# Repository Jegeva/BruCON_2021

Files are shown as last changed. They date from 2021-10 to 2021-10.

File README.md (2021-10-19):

BruCON 2021
=
This is the firmware and pcb for brucon badge 

as of released at the conference **ie. including** :

* the mistake that needs a bodge (vbat to the sensor, backlights and leds missing a bit of trace) and 
* the mistake with the connector (don't use the one refed in the kicad docs, it is keyed down instead of up)

Licenses :
=

-my (**ugly**) firmware code and the PCB are CERN-OHL-P

-the gasmask art is CC/NA by Ray Harvey

-Espressif stuff : 
[see here](https://docs.espressif.com/projects/esp-idf/en/latest/esp32/COPYRIGHT.html)

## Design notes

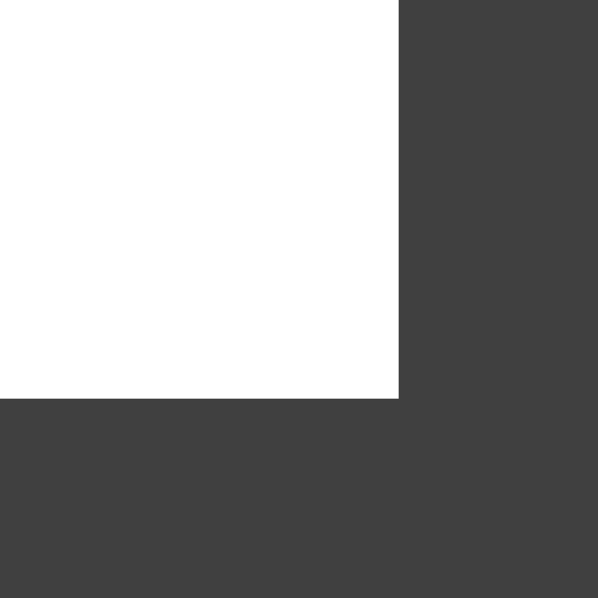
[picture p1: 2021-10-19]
pcb/.svg2shenzhen-cache/images/Dwgs.User_g1427.png

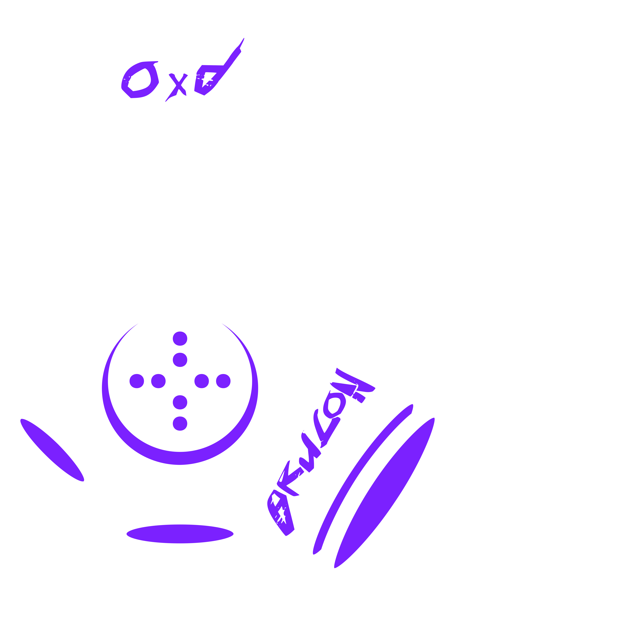
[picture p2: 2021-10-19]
pcb/.svg2shenzhen-cache/images/F.Mask_g1423.png

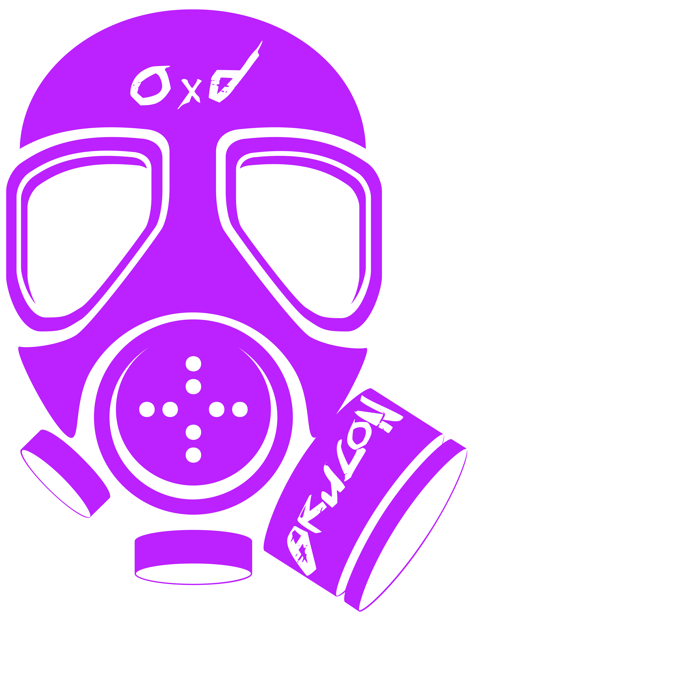
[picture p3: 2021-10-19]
pcb/.svg2shenzhen-cache/images/F.SilkS_g1425.png

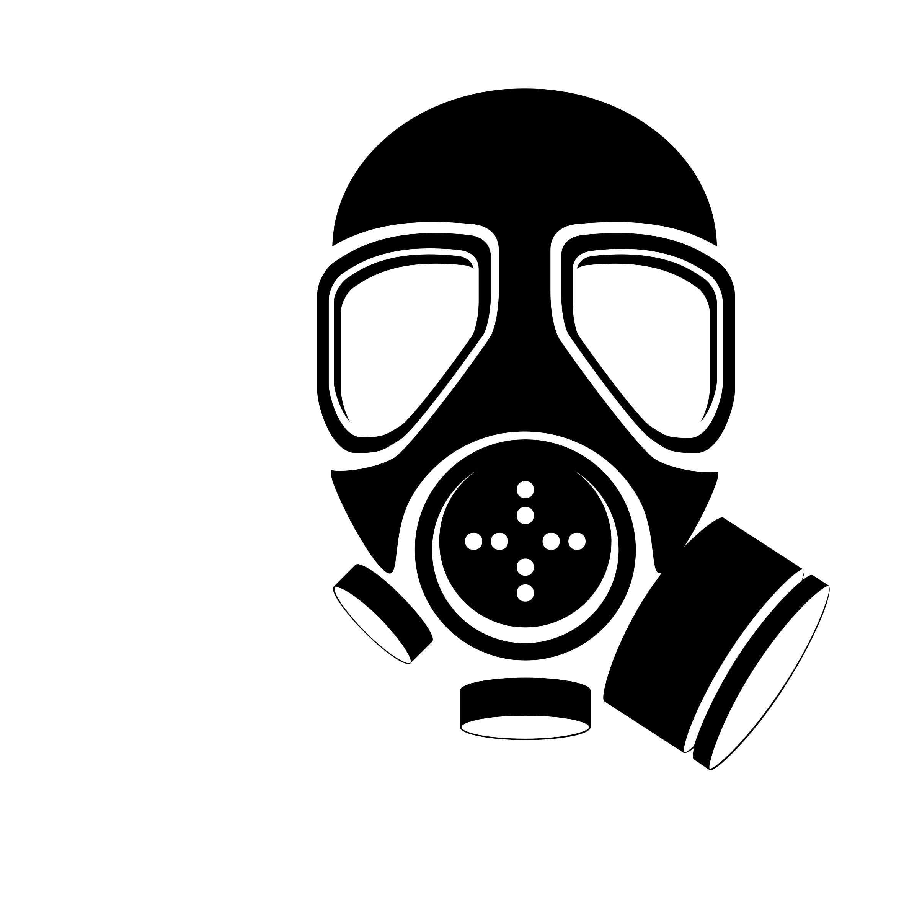
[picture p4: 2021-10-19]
pcb/.svg2shenzhen-cache/images/F.SilkS_g1537.png

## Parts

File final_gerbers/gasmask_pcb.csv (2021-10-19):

Source: | /home/jg/work/brucon/0xd/pcb/gasmask_pcb.kicad_sch
Date: | Wed Sep 15 12:33:13 2021
Tool: | Eeschema (5.99.0-10282-g296a9df530)
Generator: | /usr/local/share/kicad/plugins/bom_csv_grouped_by_value.py
Component Count: | 74
Individual Components:
Item | Qty | Reference(s) | Value | LibPart | Footprint | Datasheet
 |  | C1 | 1uF | Device:C | Capacitor_SMD:C_0805_2012Metric | ~
 |  | C2 | 1uF | Device:C | Capacitor_SMD:C_0805_2012Metric | ~
 |  | C3 | 1uF | Device:C | Capacitor_SMD:C_0805_2012Metric | ~
 |  | C4 | 4.7uF | Device:C | Capacitor_SMD:C_0805_2012Metric | ~
 |  | C5 | 0.1uF | Device:C | Capacitor_SMD:C_0805_2012Metric | ~
 |  | C6 | 4.7uF | Device:C | Capacitor_SMD:C_0805_2012Metric | ~
 |  | C7 | 0.1uF | Device:C | Capacitor_SMD:C_0805_2012Metric | ~
 |  | C9 | 4.7uF | Device:C | Capacitor_SMD:C_0805_2012Metric | ~
 |  | C10 | 4.7uF | Device:C | Capacitor_SMD:C_0805_2012Metric | ~
 |  | C11 | 10uF | Device:C | Capacitor_SMD:C_0805_2012Metric | ~
 |  | C13 | 10uF | Device:C | Capacitor_SMD:C_0805_2012Metric | ~
 |  | C14 | 10uF | Device:C | Capacitor_SMD:C_0805_2012Metric | ~
 |  | CONN_BATT1 | Conn_01x02 | Connector_Generic:Conn_01x02 | brucon_badge:JST-PH-SM4-TB-2 | ~
 |  | D1 | LED | Device:LED | LED_SMD:LED_0603_1608Metric | ~
 |  | D2 | FM5817 | Device:D_Schottky | brucon_badge:DO-214-FM5817 | ~
 |  | D3 | LED | Device:LED | LED_SMD:LED_0603_1608Metric | ~
 |  | D4 | LED_RGBA | Device:LED_RGBA | LED_SMD:LED_Cree-PLCC4_2x2mm_CW | ~
 |  | J1 | Hirose DF23C-10DS-0.5 | Connector_Generic:Conn_02x05_Counter_Clockwise | brucon_badge:DF23C-10DS-0.5V | ~
 |  | J2 | Conn_02x02_Top_Bottom | Connector_Generic:Conn_02x02_Top_Bottom | Connector_PinHeader_2.54mm:PinHeader_2x02_P2.54mm_Vertical | ~
 |  | J3 | Conn_01x02 | Connector_Generic:Conn_01x02 | Connector_PinHeader_2.54mm:PinHeader_1x02_P2.54mm_Vertical | ~
 |  | J4 | USB_B_Micro | Connector:USB_B_Micro | Connector_USB:USB_Micro-B_Molex_47346-0001 | ~
 |  | J5 | Conn_01x01_Female | Connector:Conn_01x01_Female | brucon_badge:touch_10mm | ~
 |  | J6 | Conn_01x01_Female | Connector:Conn_01x01_Female | brucon_badge:touch_10mm | ~
 |  | J7 | Conn_01x01_Female | Connector:Conn_01x01_Female | brucon_badge:touch_10mm | ~
 |  | J8 | Conn_01x01_Female | Connector:Conn_01x01_Female | brucon_badge:touch_10mm | ~
 |  | J9 | Conn_01x01_Female | Connector:Conn_01x01_Female | brucon_badge:touch_10mm | ~
 |  | J10 | Conn_01x01_Female | Connector:Conn_01x01_Female | brucon_badge:touch_10mm | ~
 |  | M2 | 10uH | BruCON_0x0a-rescue:L-adafruit | Inductor_SMD:L_0805_2012Metric
 |  | q1 | NX7002aks_small | gasmask:NX7002aks_small | Package_TO_SOT_SMD:SOT-363_SC-70-6
 |  | Q2 | BT3904 | Device:Q_NPN_BEC | Package_TO_SOT_SMD:SOT-23 | ~
 |  | Q3 | BT3904 | Device:Q_NPN_BEC | Package_TO_SOT_SMD:SOT-23 | ~
 |  | Q4 | NX7002aks_small | gasmask:NX7002aks_small | Package_TO_SOT_SMD:SOT-363_SC-70-6
 |  | R1 | 100k | Device:R | Resistor_SMD:R_0805_2012Metric | ~
 |  | R2 | 10k | Device:R | Resistor_SMD:R_0805_2012Metric | ~
 |  | R3 | 10k | Device:R | Resistor_SMD:R_0805_2012Metric | ~
 |  | R4 | 10K | Device:R | Resistor_SMD:R_0805_2012Metric | ~
 |  | R5 | 10K | Device:R | Resistor_SMD:R_0805_2012Metric | ~
 |  | R6 | 22.1k | Device:R | Resistor_SMD:R_0805_2012Metric | ~
 |  | R7 | 47.5k | Device:R | Resistor_SMD:R_0805_2012Metric | ~
 |  | R8 | 1.0k 1% | Device:R | Resistor_SMD:R_0805_2012Metric | ~
 |  | R9 | 1.0k 1% | Device:R | Resistor_SMD:R_0805_2012Metric | ~
 |  | R10 | 1.0k 1% | Device:R | Resistor_SMD:R_0805_2012Metric | ~
 |  | R11 | 1 M | Device:R | Resistor_SMD:R_0805_2012Metric | ~
 |  | R12 | 10k | Device:R | Resistor_SMD:R_0805_2012Metric | ~
 |  | R13 | 100k 1% | Device:R | Resistor_SMD:R_0805_2012Metric | ~
 |  | R14 | 100k 1% | Device:R | Resistor_SMD:R_0805_2012Metric | ~
 |  | R15 | 2k 1% | Device:R | Resistor_SMD:R_0805_2012Metric | ~
 |  | R16 | 9.0k 1% | Device:R | Resistor_SMD:R_0805_2012Metric | ~
 |  | R17 | 1.5k 1% | Device:R | Resistor_SMD:R_0805_2012Metric | ~
 |  | R18 | 2k 1% | Device:R | Resistor_SMD:R_0805_2012Metric | ~
 |  | R19 | 27k 1% | Device:R | Resistor_SMD:R_0805_2012Metric | ~
 |  | R20 | 100k 1% | Device:R | Resistor_SMD:R_0805_2012Metric | ~
 |  | R21 | 1.47k 1% | Device:R | Resistor_SMD:R_0805_2012Metric | ~
 |  | R22 | 1.47k 1% | Device:R | Resistor_SMD:R_0805_2012Metric | ~
 |  | R23 | 10k 1% | Device:R | Resistor_SMD:R_0805_2012Metric | ~
 |  | R24 | 5k 1% | Device:R | Resistor_SMD:R_0805_2012Metric | ~
 |  | R25 | 100 | Device:R | Resistor_SMD:R_0805_2012Metric | ~
 |  | R26 | 1k 1% | Device:R | Resistor_SMD:R_0805_2012Metric | ~
 |  | R27 | 50 | Device:R | Resistor_SMD:R_0805_2012Metric | ~
 |  | R28 | 5k | Device:R | Resistor_SMD:R_0805_2012Metric | ~
 |  | R29 | 10k | Device:R | Resistor_SMD:R_0805_2012Metric | ~
 |  | R30 | 10k | Device:R | Resistor_SMD:R_0805_2012Metric | ~
 |  | R31 | 20k 1% | Device:R | Resistor_SMD:R_0805_2012Metric | ~
 |  | R32 | 50 | Device:R | Resistor_SMD:R_0805_2012Metric | ~
 |  | SW1 | SW_DPDT_x2 | Switch:SW_DPDT_x2 | brucon_badge:JS102000-SAQN | ~
 |  | SW_PROG1 | SW_SPST | Switch:SW_SPST | brucon_badge:FSM4JSMATR | ~
 |  | SW_RESET1 | SW_SPST | Switch:SW_SPST | brucon_badge:FSM4JSMATR | ~
 |  | U1 | ESP32-WROOM | ESP32-footprints-Shem-Lib:ESP32-WROOM | brucon_badge:ESP32-WROOM
 |  | U2 | CP2102N-A01-GQFN24 | Interface_USB:CP2102N-A01-GQFN24 | Package_DFN_QFN:QFN-24-1EP_4x4mm_P0.5mm_EP2.6x2.6mm | http://www.silabs.com/support%20documents/technicaldocs/cp2102n-datasheet.pdf
 |  | U3 | NCP5661 | BruCON_0x0a-rescue:NCP5661-Brucon | brucon_badge:DFN6-3.6x2.15mmP0.95
 |  | U4 | LM3658SD | LM3658SD:LM3658SD | IC_TPS61087DSCR
 |  | U5 | MIC2288YD5 | BruCON_0x0a-rescue:MIC2288YD5-Brucon | Package_TO_SOT_SMD:SOT-23-5
 |  | U6 | MQ-6 | Sensor_Gas:MQ-6 | brucon_badge:MQ-3 | https://www.winsen-sensor.com/d/files/semiconductor/mq-6.pdf
 |  | U8 | MCP112-315 | BruCON_0x0a-rescue:MCP112-315-Brucon | Package_TO_SOT_SMD:SOT-23
Collated Components:
Item | Qty | Reference(s) | Value | LibPart | Footprint | Datasheet
1 | 3 | C1, C2, C3 | 1uF | Device:C | Capacitor_SMD:C_0805_2012Metric | ~
2 | 4 | C4, C6, C9, C10 | 4.7uF | Device:C | Capacitor_SMD:C_0805_2012Metric | ~
3 | 2 | C5, C7 | 0.1uF | Device:C | Capacitor_SMD:C_0805_2012Metric | ~
4 | 3 | C11, C13, C14 | 10uF | Device:C | Capacitor_SMD:C_0805_2012Metric | ~
5 | 1 | CONN_BATT1 | Conn_01x02 | Connector_Generic:Conn_01x02 | brucon_badge:JST-PH-SM4-TB-2 | ~
6 | 2 | D1, D3 | LED | Device:LED | LED_SMD:LED_0603_1608Metric | ~
7 | 1 | D2 | FM5817 | Device:D_Schottky | brucon_badge:DO-214-FM5817 | ~
8 | 1 | D4 | LED_RGBA | Device:LED_RGBA | LED_SMD:LED_Cree-PLCC4_2x2mm_CW | ~
9 | 1 | J1 | Hirose DF23C-10DS-0.5 | Connector_Generic:Conn_02x05_Counter_Clockwise | brucon_badge:DF23C-10DS-0.5V | ~
10 | 1 | J2 | Conn_02x02_Top_Bottom | Connector_Generic:Conn_02x02_Top_Bottom | Connector_PinHeader_2.54mm:PinHeader_2x02_P2.54mm_Vertical | ~
11 | 1 | J3 | Conn_01x02 | Connector_Generic:Conn_01x02 | Connector_PinHeader_2.54mm:PinHeader_1x02_P2.54mm_Vertical | ~
12 | 1 | J4 | USB_B_Micro | Connector:USB_B_Micro | Connector_USB:USB_Micro-B_Molex_47346-0001 | ~
13 | 6 | J5, J6, J7, J8, J9, J10 | Conn_01x01_Female | Connector:Conn_01x01_Female | brucon_badge:touch_10mm | ~
14 | 1 | M2 | 10uH | BruCON_0x0a-rescue:L-adafruit | Inductor_SMD:L_0805_2012Metric
15 | 2 | q1, Q4 | NX7002aks_small | gasmask:NX7002aks_small | Package_TO_SOT_SMD:SOT-363_SC-70-6
16 | 2 | Q2, Q3 | BT3904 | Device:Q_NPN_BEC | Package_TO_SOT_SMD:SOT-23 | ~
17 | 1 | R1 | 100k | Device:R | Resistor_SMD:R_0805_2012Metric | ~
18 | 5 | R2, R3, R12, R29, R30 | 10k | Device:R | Resistor_SMD:R_0805_2012Metric | ~
19 | 2 | R4, R5 | 10K | Device:R | Resistor_SMD:R_0805_2012Metric | ~
20 | 1 | R6 | 22.1k | Device:R | Resistor_SMD:R_0805_2012Metric | ~
21 | 1 | R7 | 47.5k | Device:R | Resistor_SMD:R_0805_2012Metric | ~
22 | 3 | R8, R9, R10 | 1.0k 1% | Device:R | Resistor_SMD:R_0805_2012Metric | ~
23 | 1 | R11 | 1 M | Device:R | Resistor_SMD:R_0805_2012Metric | ~
24 | 3 | R13, R14, R20 | 100k 1% | Device:R | Resistor_SMD:R_0805_2012Metric | ~
25 | 2 | R15, R18 | 2k 1% | Device:R | Resistor_SMD:R_0805_2012Metric | ~
26 | 1 | R16 | 9.0k 1% | Device:R | Resistor_SMD:R_0805_2012Metric | ~
27 | 1 | R17 | 1.5k 1% | Device:R | Resistor_SMD:R_0805_2012Metric | ~
28 | 1 | R19 | 27k 1% | Device:R | Resistor_SMD:R_0805_2012Metric | ~
29 | 2 | R21, R22 | 1.47k 1% | Device:R | Resistor_SMD:R_0805_2012Metric | ~
30 | 1 | R23 | 10k 1% | Device:R | Resistor_SMD:R_0805_2012Metric | ~
31 | 1 | R24 | 5k 1% | Device:R | Resistor_SMD:R_0805_2012Metric | ~
32 | 1 | R25 | 100 | Device:R | Resistor_SMD:R_0805_2012Metric | ~
33 | 1 | R26 | 1k 1% | Device:R | Resistor_SMD:R_0805_2012Metric | ~
34 | 2 | R27, R32 | 50 | Device:R | Resistor_SMD:R_0805_2012Metric | ~
35 | 1 | R28 | 5k | Device:R | Resistor_SMD:R_0805_2012Metric | ~
36 | 1 | R31 | 20k 1% | Device:R | Resistor_SMD:R_0805_2012Metric | ~
37 | 1 | SW1 | SW_DPDT_x2 | Switch:SW_DPDT_x2 | brucon_badge:JS102000-SAQN | ~
38 | 2 | SW_PROG1, SW_RESET1 | SW_SPST | Switch:SW_SPST | brucon_badge:FSM4JSMATR | ~
39 | 1 | U1 | ESP32-WROOM | ESP32-footprints-Shem-Lib:ESP32-WROOM | brucon_badge:ESP32-WROOM
40 | 1 | U2 | CP2102N-A01-GQFN24 | Interface_USB:CP2102N-A01-GQFN24 | Package_DFN_QFN:QFN-24-1EP_4x4mm_P0.5mm_EP2.6x2.6mm | http://www.silabs.com/support%20documents/technicaldocs/cp2102n-datasheet.pdf
41 | 1 | U3 | NCP5661 | BruCON_0x0a-rescue:NCP5661-Brucon | brucon_badge:DFN6-3.6x2.15mmP0.95
42 | 1 | U4 | LM3658SD | LM3658SD:LM3658SD | IC_TPS61087DSCR
43 | 1 | U5 | MIC2288YD5 | BruCON_0x0a-rescue:MIC2288YD5-Brucon | Package_TO_SOT_SMD:SOT-23-5
44 | 1 | U6 | MQ-6 | Sensor_Gas:MQ-6 | brucon_badge:MQ-3 | https://www.winsen-sensor.com/d/files/semiconductor/mq-6.pdf
45 | 1 | U8 | MCP112-315 | BruCON_0x0a-rescue:MCP112-315-Brucon | Package_TO_SOT_SMD:SOT-23

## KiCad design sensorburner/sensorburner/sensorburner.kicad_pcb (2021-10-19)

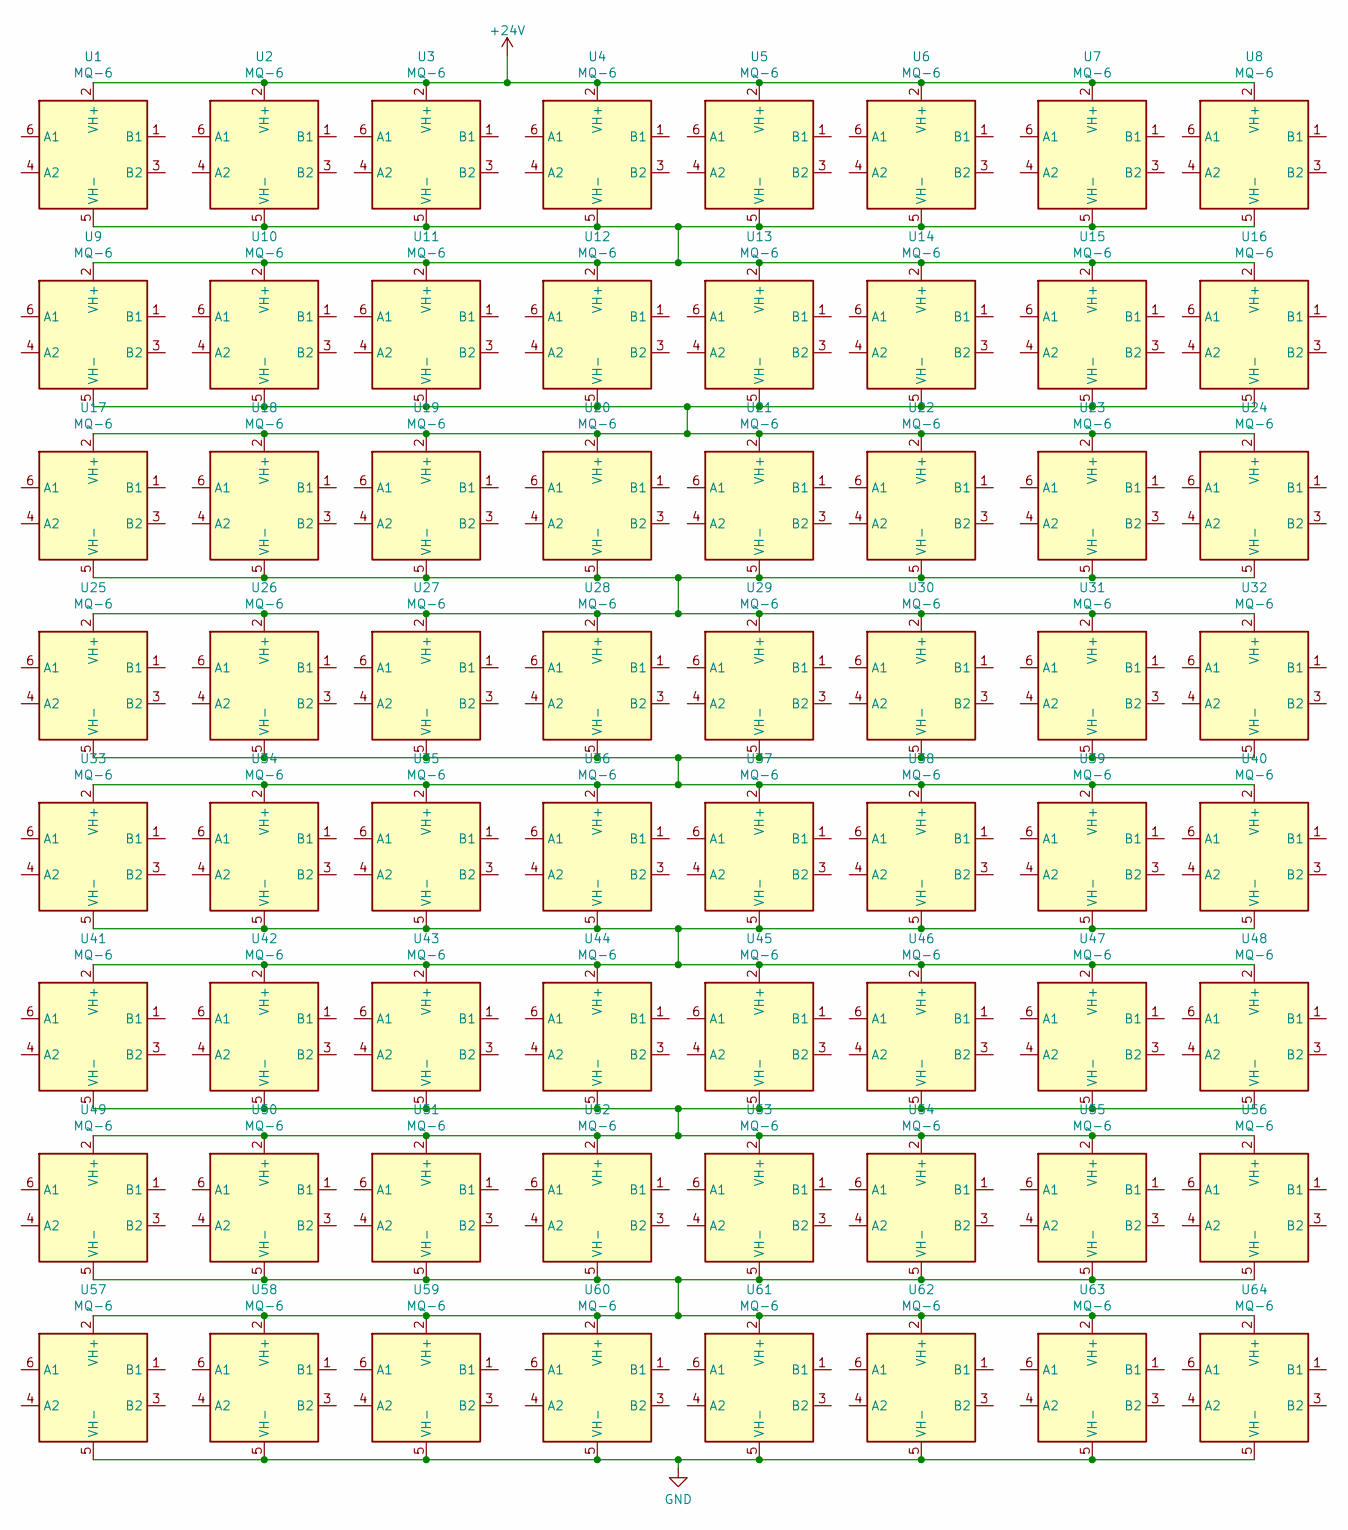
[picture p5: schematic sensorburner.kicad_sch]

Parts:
U1, U2, U3, U4, U5, U6, U7, U8, U9, U10, U11, U12, U13, U14, U15, U16, U17, U18, U19, U20, U21, U22, U23, U24, U25, U26, U27, U28, U29, U30, U31, U32, U33, U34, U35, U36, U37, U38, U39, U40, U41, U42, U43, U44, U45, U46, U47, U48, U49, U50, U51, U52, U53, U54, U55, U56, U57, U58, U59, U60, U61, U62, U63, U64: MQ-6; MQ-3-sparkfuntight

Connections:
+24V: U1.2 (VH+), U2.2 (VH+), U3.2 (VH+), U4.2 (VH+), U5.2 (VH+), U6.2 (VH+), U7.2 (VH+), U8.2 (VH+)
GND: U57.5 (VH-), U58.5 (VH-), U59.5 (VH-), U60.5 (VH-), U61.5 (VH-), U62.5 (VH-), U63.5 (VH-), U64.5 (VH-)
unnamed: U1.5 (VH-), U2.5 (VH-), U3.5 (VH-), U4.5 (VH-), U5.5 (VH-), U6.5 (VH-), U7.5 (VH-), U8.5 (VH-), U9.2 (VH+), U10.2 (VH+), U11.2 (VH+), U12.2 (VH+), U13.2 (VH+), U14.2 (VH+), U15.2 (VH+), U16.2 (VH+)
unnamed: U9.5 (VH-), U10.5 (VH-), U11.5 (VH-), U12.5 (VH-), U13.5 (VH-), U14.5 (VH-), U15.5 (VH-), U16.5 (VH-), U17.2 (VH+), U18.2 (VH+), U19.2 (VH+), U20.2 (VH+), U21.2 (VH+), U22.2 (VH+), U23.2 (VH+), U24.2 (VH+)
unnamed: U17.5 (VH-), U18.5 (VH-), U19.5 (VH-), U20.5 (VH-), U21.5 (VH-), U22.5 (VH-), U23.5 (VH-), U24.5 (VH-), U25.2 (VH+), U26.2 (VH+), U27.2 (VH+), U28.2 (VH+), U29.2 (VH+), U30.2 (VH+), U31.2 (VH+), U32.2 (VH+)
unnamed: U25.5 (VH-), U26.5 (VH-), U27.5 (VH-), U28.5 (VH-), U29.5 (VH-), U30.5 (VH-), U31.5 (VH-), U32.5 (VH-), U33.2 (VH+), U34.2 (VH+), U35.2 (VH+), U36.2 (VH+), U37.2 (VH+), U38.2 (VH+), U39.2 (VH+), U40.2 (VH+)
unnamed: U33.5 (VH-), U34.5 (VH-), U35.5 (VH-), U36.5 (VH-), U37.5 (VH-), U38.5 (VH-), U39.5 (VH-), U40.5 (VH-), U41.2 (VH+), U42.2 (VH+), U43.2 (VH+), U44.2 (VH+), U45.2 (VH+), U46.2 (VH+), U47.2 (VH+), U48.2 (VH+)
unnamed: U41.5 (VH-), U42.5 (VH-), U43.5 (VH-), U44.5 (VH-), U45.5 (VH-), U46.5 (VH-), U47.5 (VH-), U48.5 (VH-), U49.2 (VH+), U50.2 (VH+), U51.2 (VH+), U52.2 (VH+), U53.2 (VH+), U54.2 (VH+), U55.2 (VH+), U56.2 (VH+)
unnamed: U49.5 (VH-), U50.5 (VH-), U51.5 (VH-), U52.5 (VH-), U53.5 (VH-), U54.5 (VH-), U55.5 (VH-), U56.5 (VH-), U57.2 (VH+), U58.2 (VH+), U59.2 (VH+), U60.2 (VH+), U61.2 (VH+), U62.2 (VH+), U63.2 (VH+), U64.2 (VH+)

Board: 2 copper layers, 64 parts (0 on the bottom side), 9 nets, no tracks yet.

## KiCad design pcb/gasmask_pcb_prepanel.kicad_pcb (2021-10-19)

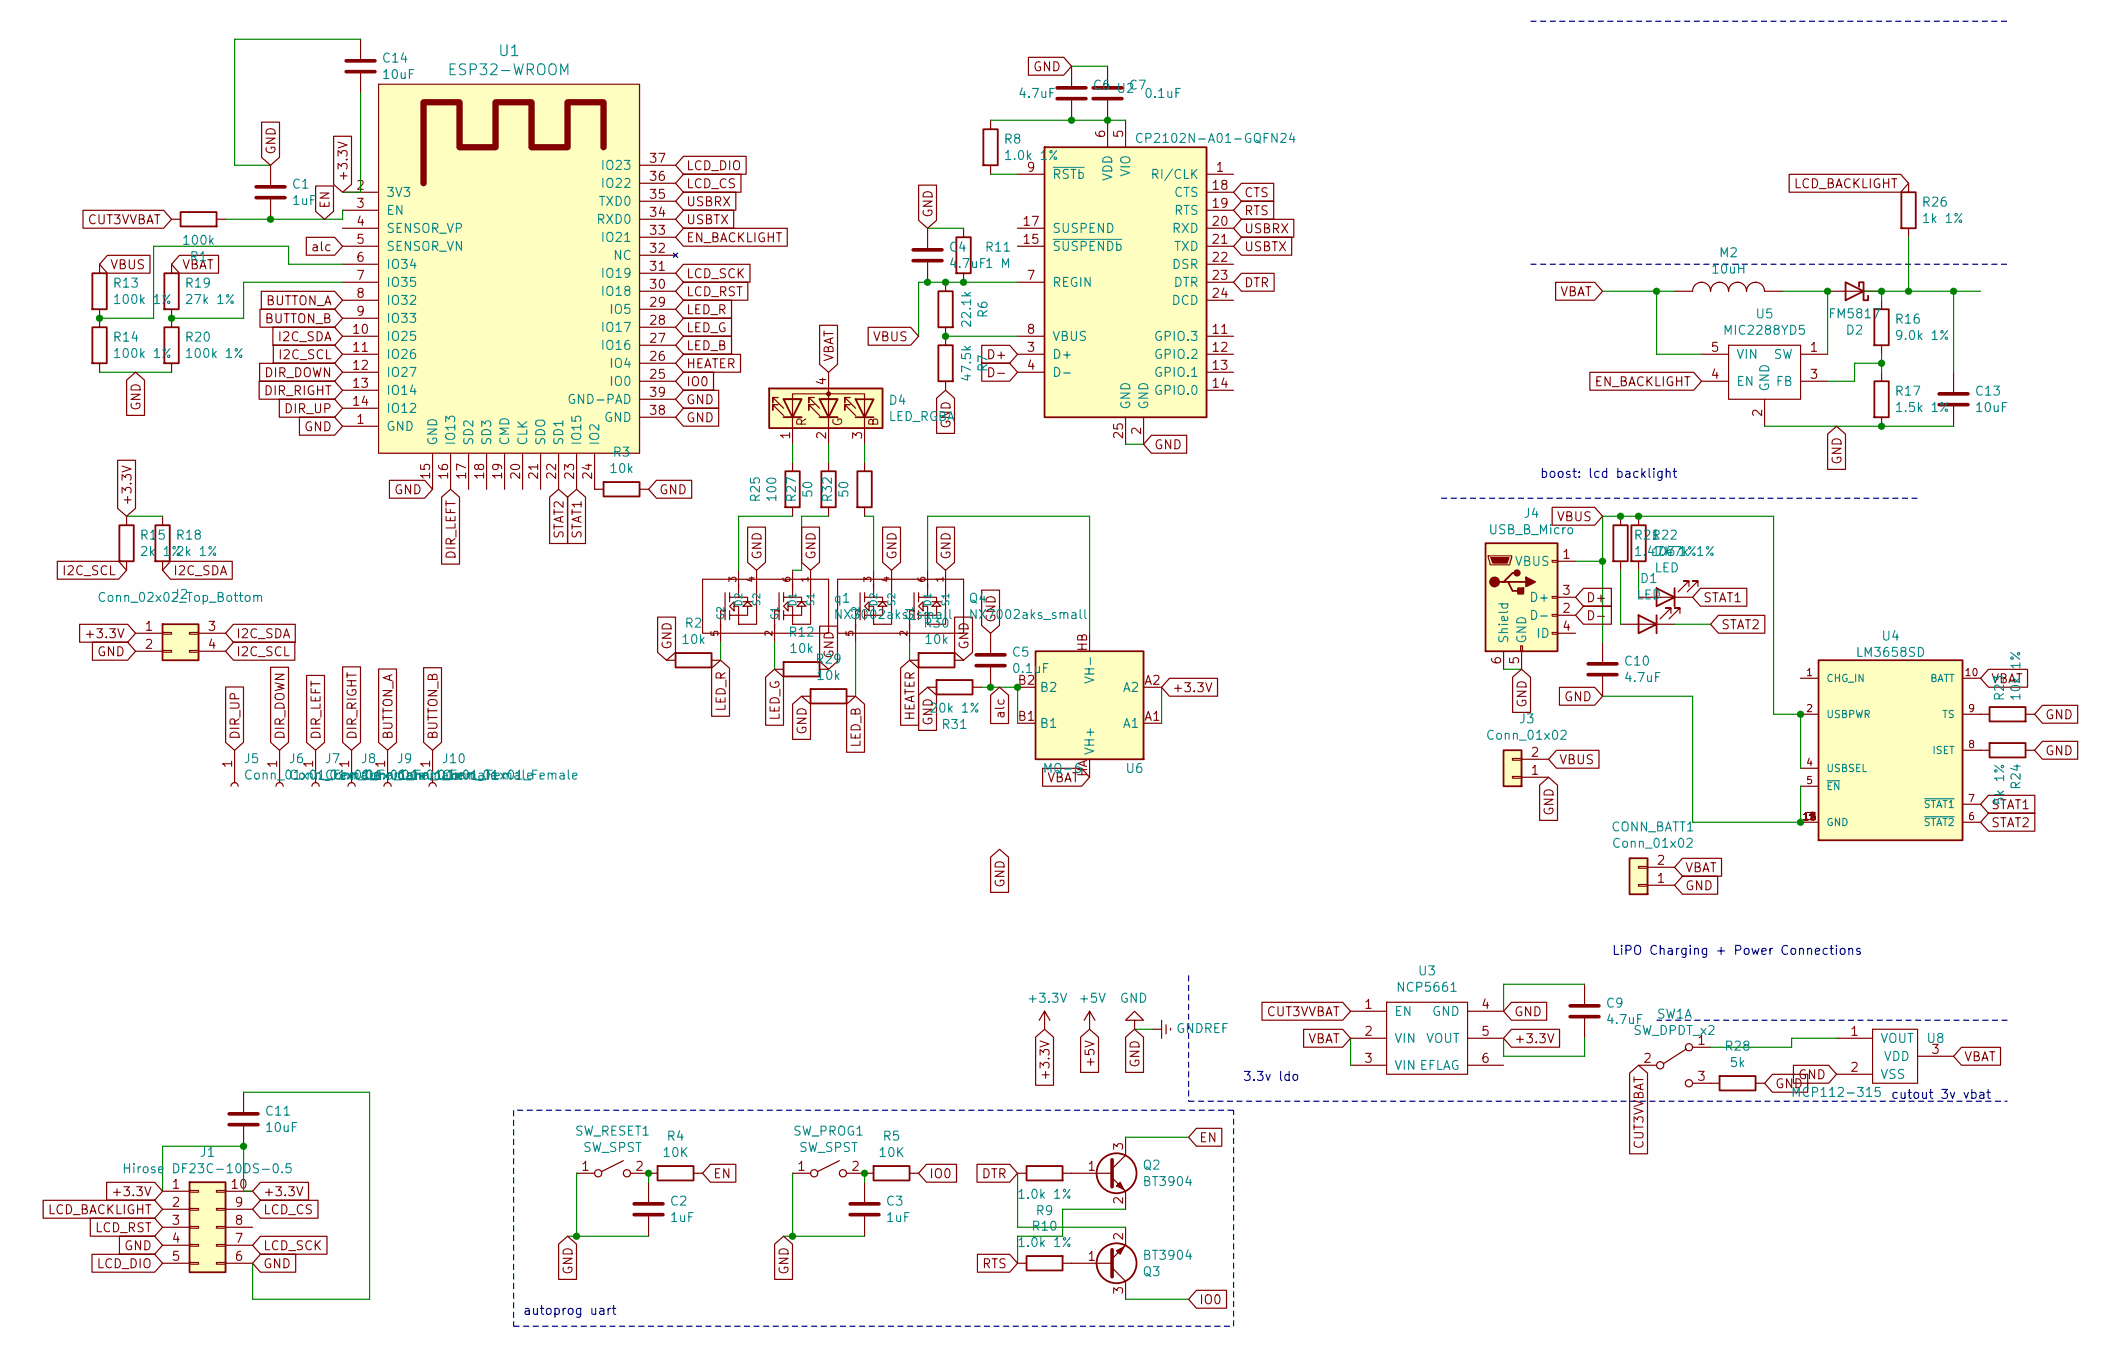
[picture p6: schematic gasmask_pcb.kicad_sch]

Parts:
C1, C2, C3: 1uF; C_0805_2012Metric
C4, C6, C9, C10: 4.7uF; C_0805_2012Metric
C5, C7: 0.1uF; C_0805_2012Metric
C11, C13, C14: 10uF; C_0805_2012Metric
CONN_BATT1: Conn_01x02; JST-PH-SM4-TB-2
D1, D3: LED; LED_0603_1608Metric
D2: FM5817; DO-214-FM5817
D4: LED_RGBA; LED_Cree-PLCC4_2x2mm_CW
J1: Hirose DF23C-10DS-0.5; DF23C-10DS-0.5V
J2: Conn_02x02_Top_Bottom; PinHeader_2x02_P2.54mm_Vertical
J3: Conn_01x02; PinHeader_1x02_P2.54mm_Vertical
J4: USB_B_Micro; USB_Micro-B_Molex_47346-0001
J5, J6, J7, J8, J9, J10: Conn_01x01_Female; touch_10mm
M2: 10uH; L_0805_2012Metric
Q2, Q3: BT3904; SOT-23
Q4: NX7002aks_small; SOT-363_SC-70-6
R1: 100k; R_0805_2012Metric
R2, R3, R12, R29, R30: 10k; R_0805_2012Metric
R4, R5: 10K; R_0805_2012Metric
R6: 22.1k; R_0805_2012Metric
R7: 47.5k; R_0805_2012Metric
R8, R9, R10: 1.0k 1%; R_0805_2012Metric
R11: 1 M; R_0805_2012Metric
R13, R14, R20: 100k 1%; R_0805_2012Metric
R15, R18: 2k 1%; R_0805_2012Metric
R16: 9.0k 1%; R_0805_2012Metric
R17: 1.5k 1%; R_0805_2012Metric
R19: 27k 1%; R_0805_2012Metric
R21, R22: 1.47k 1%; R_0805_2012Metric
R23: 10k 1%; R_0805_2012Metric
R24: 5k 1%; R_0805_2012Metric
R25: 100; R_0805_2012Metric
R26: 1k 1%; R_0805_2012Metric
R27, R32: 50; R_0805_2012Metric
R28: 5k; R_0805_2012Metric
R31: 20k 1%; R_0805_2012Metric
SW1: SW_DPDT_x2; JS102000-SAQN
SW_PROG1: SW_SPST; FSM4JSMATR
SW_RESET1: SW_SPST; FSM4JSMATR
U1: ESP32-WROOM
U2: CP2102N-A01-GQFN24; QFN-24-1EP_4x4mm_P0.5mm_EP2.6x2.6mm
U3: NCP5661; DFN6-3.6x2.15mmP0.95
U4: LM3658SD; IC_TPS61087DSCR
U5: MIC2288YD5; SOT-23-5
U6: MQ-6; MQ-3
U8: MCP112-315; SOT-23
q1: NX7002aks_small; SOT-363_SC-70-6

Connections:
+3.3V: C9.2, C11.2, C14.2, J1.1, J1.10, J2.1, R15.1, R18.1, U1.2 (3V3), U3.5 (VOUT), U6.A1, U6.A2
BUTTON_A: J9.1, U1.8 (IO32)
BUTTON_B: J10.1, U1.9 (IO33)
CTS: U2.18 (CTS)
CUT3VVBAT: R1.1, SW1.2 (B), U3.1 (EN)
D+: J4.3 (D+), U2.3 (D+)
D-: J4.2 (D-), U2.4 (D-)
DIR_DOWN: J6.1, U1.12 (IO27)
DIR_LEFT: J7.1, U1.16 (IO13)
DIR_RIGHT: J8.1, U1.13 (IO14)
DIR_UP: J5.1, U1.14 (IO12)
DTR: Q3.2 (E), R9.1, U2.23 (DTR)
EN: C1.2, Q2.3 (C), R1.2, R4.1, U1.3 (EN)
EN_BACKLIGHT: U1.33 (IO21), U5.4 (EN)
HEATER: Q4.2 (G1), R30.2, U1.26 (IO4)
I2C_SCL: J2.4, R15.2, U1.11 (IO26)
I2C_SDA: J2.3, R18.2, U1.10 (IO25)
IO0: Q3.3 (C), R5.1, U1.25 (IO0)
LCD_BACKLIGHT: J1.2, R26.1
LCD_CS: J1.9, U1.36 (IO22)
LCD_DIO: J1.5, U1.37 (IO23)
LCD_RST: J1.3, U1.30 (IO18)
LCD_SCK: J1.7, U1.31 (IO19)
LED_B: Q4.5 (G2), R29.1, U1.27 (IO16)
LED_G: R12.2, U1.28 (IO17), q1.2 (G1)
LED_R: R2.1, U1.29 (IO5), q1.5 (G2)
unnamed: C2.1, R4.2, SW_RESET1.2 (B)
unnamed: C3.1, R5.2, SW_PROG1.2 (B)
unnamed: C6.2, C7.2, R8.1, U2.5 (VIO), U2.6 (VDD)
unnamed: C13.1, D2.1 (K), R16.1, R26.2
unnamed: D1.2 (A), R21.2
unnamed: D2.2 (A), M2.2, U5.1 (SW)
unnamed: D3.2 (A), R22.2
unnamed: D4.1 (RK), R25.1
unnamed: D4.2 (GK), R27.1
unnamed: D4.3 (BK), R32.1
unnamed: Q2.1 (B), R9.2
unnamed: Q3.1 (B), R10.2
unnamed: Q4.3 (D2), R32.2
unnamed: Q4.6 (D1), U6.HB (VH-)
unnamed: R3.2, U1.24 (IO2)
unnamed: R6.2, R7.1, U2.8 (VBUS)
unnamed: R8.2, U2.9 (~RSTb)
unnamed: R13.2, R14.1, U1.6 (IO34)
unnamed: R16.2, R17.1, U5.3 (FB)
unnamed: R19.2, R20.1, U1.7 (IO35)
unnamed: R23.1, U4.9 (TS)
unnamed: R28.2, SW1.3 (C)
unnamed: SW1.1 (A), U8.1 (VOUT)
unnamed: R25.2, q1.3 (D2)
unnamed: R27.2, q1.6 (D1)
RTS: Q2.2 (E), R10.1, U2.19 (RTS)
STAT1: D3.1 (K), U1.23 (IO15), U4.7 (~STAT1)
STAT2: D1.1 (K), U1.22 (SD1), U4.6 (~STAT2)
USBRX: U1.35 (TXD0), U2.20 (RXD)
USBTX: U1.34 (RXD0), U2.21 (TXD)
VBAT: CONN_BATT1.2, D4.4 (A), M2.1, R19.1, U3.2 (VIN), U3.3 (VIN), U4.10 (BATT), U5.5 (VIN), U6.HA (VH+), U8.3 (VDD); also elsewhere on the board
alc: C5.2, R31.1, U1.5 (SENSOR_VN), U6.B1, U6.B2

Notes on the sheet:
autoprog uart
3.3v ldo
boost: lcd backlight
LiPO Charging + Power Connections
cutout 3v vbat

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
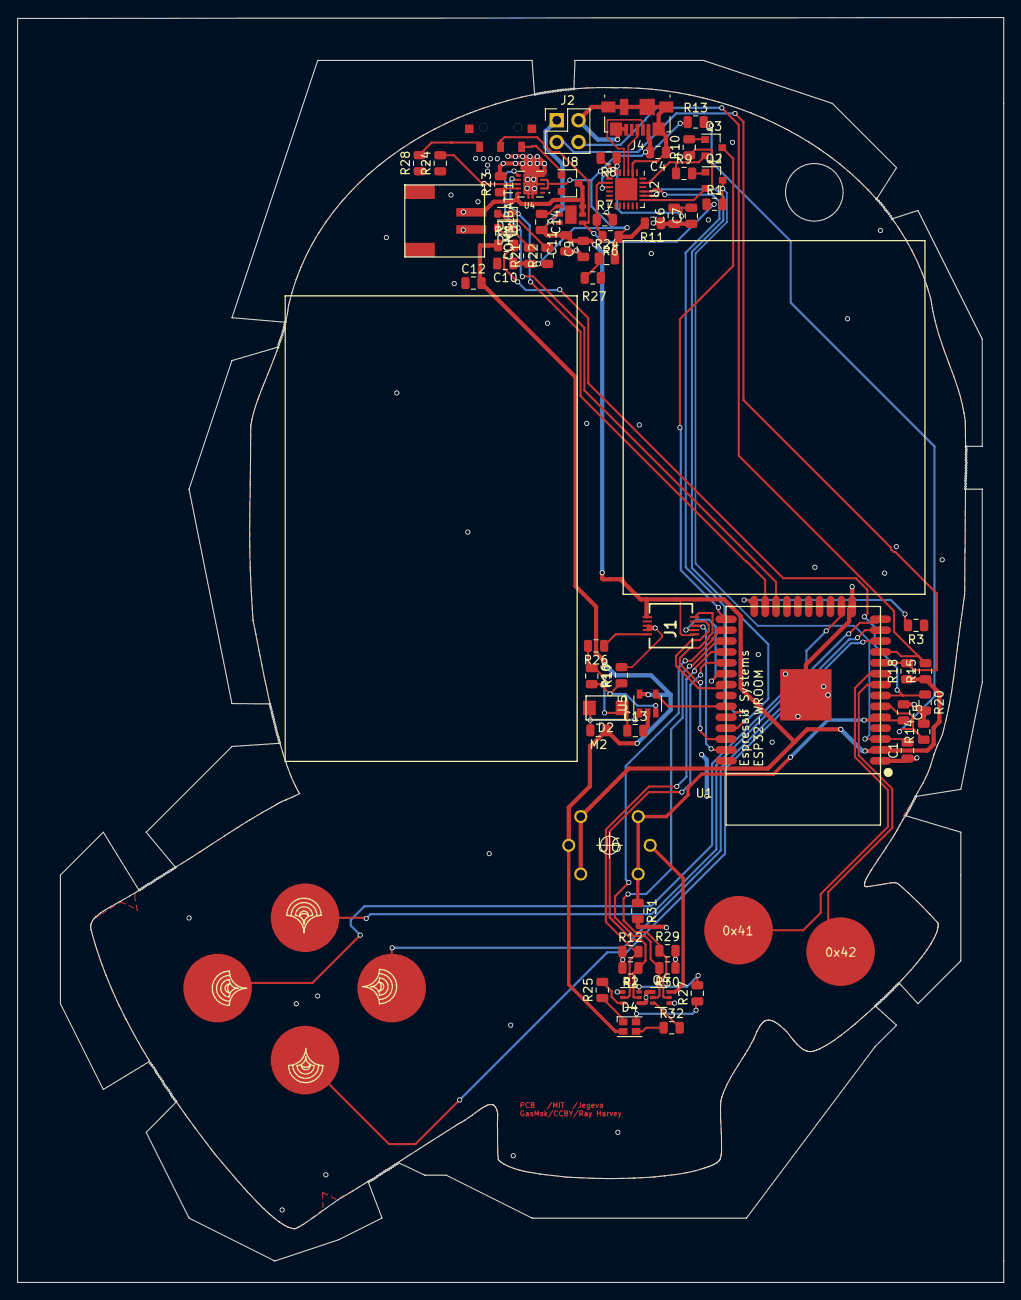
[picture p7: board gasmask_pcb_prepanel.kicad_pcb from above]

Board: 2 copper layers, 115.0 x 147.5 mm, 70 parts (0 on the bottom side), 59 nets.

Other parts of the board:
C12: 10uF; C_0805_2012Metric
R24#2: 5k 1%; R_0805_2012Metric
R27#2: 10k 1%; R_0805_2012Metric

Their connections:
VBAT: C12.2; also elsewhere on the board

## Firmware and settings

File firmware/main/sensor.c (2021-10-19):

#include "sensor.h"
#include "brucon_nvs.h"
#define DEFAULT_VREF 1100
#define NO_OF_SAMPLES 200
static esp_adc_cal_characteristics_t *adc_chars;
adc_unit_t unit = ADC_UNIT_1;
static const adc_atten_t atten = ADC_ATTEN_DB_11;
adc1_channel_t chan_sensor =ADC1_GPIO39_CHANNEL;


volatile char calAlcSens;
volatile char getAlcSens;
volatile uint16_t Alc_level;

void getSensorT();

void init_sensor (void){
    gpio_config_t io_conf;
    adc_unit_t unit = ADC_UNIT_1;
    
    adc_chars = calloc(1, sizeof(esp_adc_cal_characteristics_t));
    esp_adc_cal_characterize(
			     unit,
			     atten,
			     ADC_WIDTH_BIT_12,
			     DEFAULT_VREF,
			     adc_chars
			     );
    io_conf.intr_type = GPIO_PIN_INTR_DISABLE;
    io_conf.mode = GPIO_MODE_OUTPUT;
    io_conf.pin_bit_mask = (1<<CONFIG_HEATER_MOSFET_PIN);
    io_conf.pull_down_en = 0;
    io_conf.pull_up_en = 0;
    gpio_config(&io_conf);
    
    adc1_config_width(ADC_WIDTH_BIT_12);
    adc1_config_channel_atten(chan_sensor, ADC_ATTEN_DB_11);
}


void calAlcTask(){
  TaskHandle_t Tasktemp;
  init_sensor();
  getAlcSens=1;
  gpio_set_level(CONFIG_HEATER_MOSFET_PIN,1);
  
  TickType_t tickstart = xTaskGetTickCount();
  printf("Heating for cal");
  while((xTaskGetTickCount() -  tickstart) < 5000 ){
    printf(".\n");
    vTaskDelay(500);
  }
  printf("\n");
  xTaskCreate( &  getSensorT  , "getSensor" , 4096, NULL , 5| portPRIVILEGE_BIT , &Tasktemp);

  while(getAlcSens){
  vTaskDelay(200);
  }
  vTaskDelete(Tasktemp);
  gpio_set_level(CONFIG_HEATER_MOSFET_PIN,0);
  printf("CAL Raw: %d\n", Alc_level);
  calAlcSens=0;
  setBruCONConfigUint32("AlcCal",Alc_level);
  setBruCONConfigFlag("haveAlcCal",1);
  while(1){ vTaskDelay(1000);};
}

void sensorheat(int on){
  if(!adc_chars)
    init_sensor();
  gpio_set_level(CONFIG_HEATER_MOSFET_PIN,on);
}

void waitsensor(){
  TickType_t tickstart = xTaskGetTickCount();
  while(((xTaskGetTickCount() -  tickstart)) < (10000/portTICK_PERIOD_MS) ){
    printf("w : %d %d %d.\n",xTaskGetTickCount(),tickstart,portTICK_PERIOD_MS);
    vTaskDelay(1000);
  }
}

void getSensorT(){
  getSensor();
  while(1)
  vTaskDelay(1000);
}

uint32_t getSensor(){
  if(!adc_chars)
    init_sensor();
  uint32_t adc_reading = 0;  

  sensorheat(1);
  waitsensor();

  //Multisamplingclear


  
  for (int i = 0; i < NO_OF_SAMPLES; i++) {
    if (unit == ADC_UNIT_1) {
      adc_reading += adc1_get_raw((adc1_channel_t)chan_sensor);
    }
  }
  adc_reading /= NO_OF_SAMPLES;
  sensorheat(0);
  //Convert adc_reading to voltage in mV
  uint32_t voltage = esp_adc_cal_raw_to_voltage(adc_reading, adc_chars);
  printf("SENS Raw: %d\tVoltage: %dmV\n", adc_reading, voltage);
  Alc_level=voltage;
  getAlcSens=0;
  return(voltage);
}

uint32_t heatandgetSensor(){
   sensorheat(1);
   waitsensor();
   uint32_t r = getSensor();
   sensorheat(0);
   return(r);
}

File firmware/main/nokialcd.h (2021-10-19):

#ifndef __NOKIA_LCD_H
#define __NOKIA_LCD_H

#include <stdio.h>
#include <stdlib.h>
#include <string.h>
#include <esp32/rom/ets_sys.h>
#include "driver/spi_master.h"
#include "soc/gpio_struct.h"
#include "driver/gpio.h"
#include "battery.h"
#include "math.h"

void MapWestL(void* arg);
void MapNovoL(void* arg);



#define LCD_SCK CONFIG_NOKIA6100_LCD_GPIO_SCK
#define LCD_DIO CONFIG_NOKIA6100_LCD_GPIO_DIO
#define LCD_RST CONFIG_NOKIA6100_LCD_GPIO_RST
#define LCD_CS  CONFIG_NOKIA6100_LCD_GPIO_CS

#define ENSCR_PIN CONFIG_NOKIA6100_LCD_GPIO_BACKLIGHT


#define PIN_BL CONFIG_CROSS_PIN_BUTTON_LEFT
#define PIN_BR CONFIG_CROSS_PIN_BUTTON_RIGHT
#define PIN_BU CONFIG_CROSS_PIN_BUTTON_UP
#define PIN_BD CONFIG_CROSS_PIN_BUTTON_DOWN
#define PIN_BA CONFIG_CROSS_PIN_BUTTON_A
#define PIN_BB CONFIG_CROSS_PIN_BUTTON_B

#define PIN_NCHARGING 34

#define LCD_SCK_L gpio_set_level(LCD_SCK,0)
#define LCD_SCK_H gpio_set_level(LCD_SCK,1)
#define LCD_DIO_L gpio_set_level(LCD_DIO,0)
#define LCD_DIO_H gpio_set_level(LCD_DIO,1)
#define LCD_RST_L gpio_set_level(LCD_RST,0)
#define LCD_RST_H gpio_set_level(LCD_RST,1)
#define LCD_CS_L  gpio_set_level(LCD_CS ,0)
#define LCD_CS_H  gpio_set_level(LCD_CS ,1)

#define dl_us(x)  ets_delay_us(x)
#define clockit   LCD_SCK_L;                    \
    dl_us(1);                                   \
    LCD_SCK_H;

#define EPSON 1
#define PHILLIPS 0

#define LCD_COMMAND 0
#define LCD_DATA 1

// ripped from the arduino library

#define ROW_LENGTH	132
#define COL_HEIGHT	132

//********************************************************************
//					EPSON Controller Definitions
//********************************************************************
#define DISON       0xAF	// Display on
#define DISOFF      0xAE	// Display off
#define DISNOR      0xA6	// Normal display
#define DISINV      0xA7	// Inverse display
#define SLPIN       0x95	// Sleep in
#define SLPOUT      0x94	// Sleep out
#define COMSCN      0xBB	// Common scan direction
#define DISCTL      0xCA	// Display control
#define PASET       0x75	// Page address set
#define CASET       0x15	// Column address set
#define DATCTL      0xBC	// Data scan direction, etc.
#define RGBSET8     0xCE	// 256-color position set
#define RAMWR       0x5C	// Writing to memory
#define RAMRD       0x5D	// Reading from memory
#define PTLIN       0xA8	// Partial display in
#define PTLOUT      0xA9	// Partial display out
#define RMWIN       0xE0	// Read and modify write
#define RMWOUT      0xEE	// End
#define ASCSET      0xAA	// Area scroll set
#define SCSTART     0xAB	// Scroll start set
#define OSCON       0xD1	// Internal oscillation on
#define OSCOFF      0xD2	// Internal osciallation off
#define PWRCTR      0x20	// Power control
#define VOLCTR      0x81	// Electronic volume control
#define VOLUP       0xD6	// Increment electronic control by 1
#define VOLDOWN     0xD7	// Decrement electronic control by 1
#define TMPGRD      0x82	// Temperature gradient set
#define EPCTIN      0xCD	// Control EEPROM
#define EPCOUT      0xCC	// Cancel EEPROM control
#define EPMWR       0xFC	// Write into EEPROM
#define EPMRD       0xFD	// Read from EEPROM
#define EPSRRD1     0x7C	// Read register 1
#define EPSRRD2     0x7D	// Read register 2
#define NOP         0x25	// No op

//********************************************************************
//			PHILLIPS Controller Definitions
//********************************************************************
//LCD Commands
#define	NOPP		0x00	// No operation
#define	BSTRON		0x03	// Booster voltage on
#define SLEEPIN     0x10	// Sleep in
#define	SLEEPOUT	0x11	// Sleep out
#define	NORON		0x13	// Normal display mode on
#define	INVOFF		0x20	// Display inversion off
#define INVON      	0x21	// Display inversion on
#define	SETCON		0x25	// Set contrast
#define DISPOFF     0x28	// Display off
#define DISPON      0x29	// Display on
#define CASETP      0x2A	// Column address set
#define PASETP      0x2B	// Page address set
#define RAMWRP      0x2C	// Memory write
#define RGBSET	    0x2D	// Color set
#define	MADCTL		0x36	// Memory data access control
#define	PCOLMOD		0x3A	// Interface pixel format
#define DISCTR      0xB9	// Super frame inversion
#define	EC			0xC0	// Internal or external oscillator

//*******************************************************
//				12-Bit Color Definitions
//*******************************************************
#define B12_BLACK	    0xF000
#define B12_NAVY 		0xF008
#define B12_BLUE		0xF00F
#define B12_TEAL 		0xF088
#define B12_EMERALD		0xF0C5
#define	B12_GREEN		0xF0F0
#define B12_CYAN		0xF0FF
#define B12_SLATE 		0xF244
#define B12_INDIGO  	0xF408
#define B12_TURQUOISE	0xF4ED
#define B12_OLIVE 		0xF682
#define B12_MAROON 		0xF800
#define B12_PURPLE 		0xF808
#define B12_GRAY 		0xF888
#define B12_SKYBLUE		0xF8CE
#define B12_BROWN		0xFB22
#define B12_CRIMSON 	0xFD13
#define B12_ORCHID 		0xFD7D
#define B12_RED			0xFF00
#define B12_MAGENTA		0xFF0F
#define B12_ORANGE 		0xFF40
#define B12_PINK		0xFF6A
#define B12_CORAL 		0xFF75
#define B12_SALMON 		0xFF87
#define B12_GOLD 		0xFFD0
#define B12_YELLOW		0xFFF0
#define B12_WHITE		0xFFFF

//*******************************************************
//                              Circle Definitions
//*******************************************************
#define FULLCIRCLE 1
#define OPENSOUTH  2
#define OPENNORTH  3
#define OPENEAST   4
#define OPENWEST   5
#define OPENNORTHEAST 6
#define OPENNORTHWEST 7
#define OPENSOUTHEAST 8
#define OPENSOUTHWEST 9
#define FILL 0
#define ESE 1
#define ENE 2
#define WSW 3
#define WNW 4
#define SSE 5
#define NNE 6
#define SSW 7
#define NNW 8

#define ROW_LENGTH	132
#define COL_HEIGHT	132

void init_lcd(int type);
void switchbacklight(int state);
void lcd_clearB12(uint16_t color);

void lcd_contrast(char setting);
void lcd_setArc(int x0, int y0, int radius, int arcSegments[], int numSegments, int lineThickness, int color);
void lcd_setCircle (int x0, int y0, int radius, int color, int lineThickness);
void lcd_setChar(char c, int x, int y, int fColor, int bColor, char uselastfill);
void lcd_setStr(char *pString, int x, int y, int fColor, int bColor, char uselastfill, char newline);
void lcd_setLine(int x0, int y0, int x1, int y1, int color);
void lcd_setRect(int x0, int y0, int x1, int y1, unsigned char fill, int color);
void lcd_printLogo(void);
void lcd_printBMP(char * image_main); //prints an image (BMP);
void lcd_off(void);
void lcd_on(void);
void lcd_sync(void);
void bruconlogo();

typedef uint16_t pixel_t;

typedef struct image_s {
    int w;
    int h;
    pixel_t buffer[];
} image_t;

void draw_pixel(int x, int y, pixel_t color, unsigned int blend);
void draw_image(const image_t * img, int x, int y);
uint32_t VivaLaVodkaL(void* arg);

typedef struct {
    const uint16_t * data;
    const uint16_t * lookup;
    const uint16_t height;
    const uint16_t min;
    const uint16_t max;
} font_t;
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
